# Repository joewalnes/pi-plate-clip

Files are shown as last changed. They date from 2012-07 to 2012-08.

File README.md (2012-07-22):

Pi Plate Clip
=============

An accessory for the [Adafruit's Prototyping Pi Plate](http://www.adafruit.com/products/801)
for the [Raspberry Pi](http://www.raspberrypi.org/).

These are plastic clips that can be used to add additional support, so when you push
wires into the board, it does not bend and damage the Pi connection pins.

Designed to be cut out of acryllic using a laser cutter.

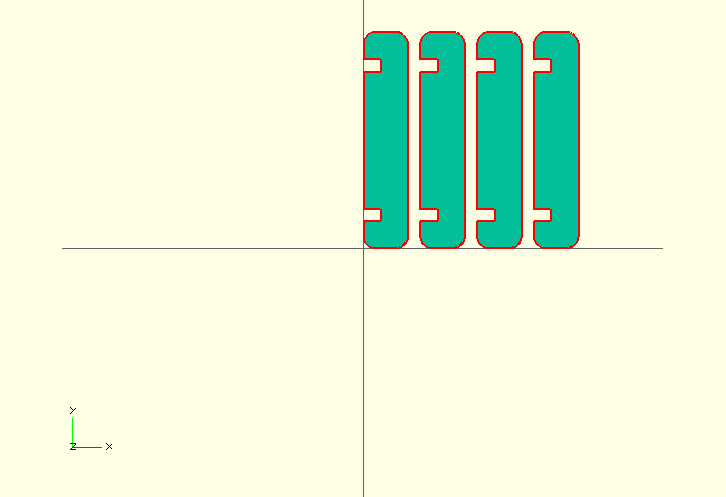
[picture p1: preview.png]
Pi Plate Clip Preview


License: [Creative Commons Attribution 3.0 Unported](http://creativecommons.org/licenses/by/3.0/)

-  **Joe Walnes**: [@joewalnes](http://twitter.com/joewalnes) | [joewalnes.com](http://joewalnes.com)

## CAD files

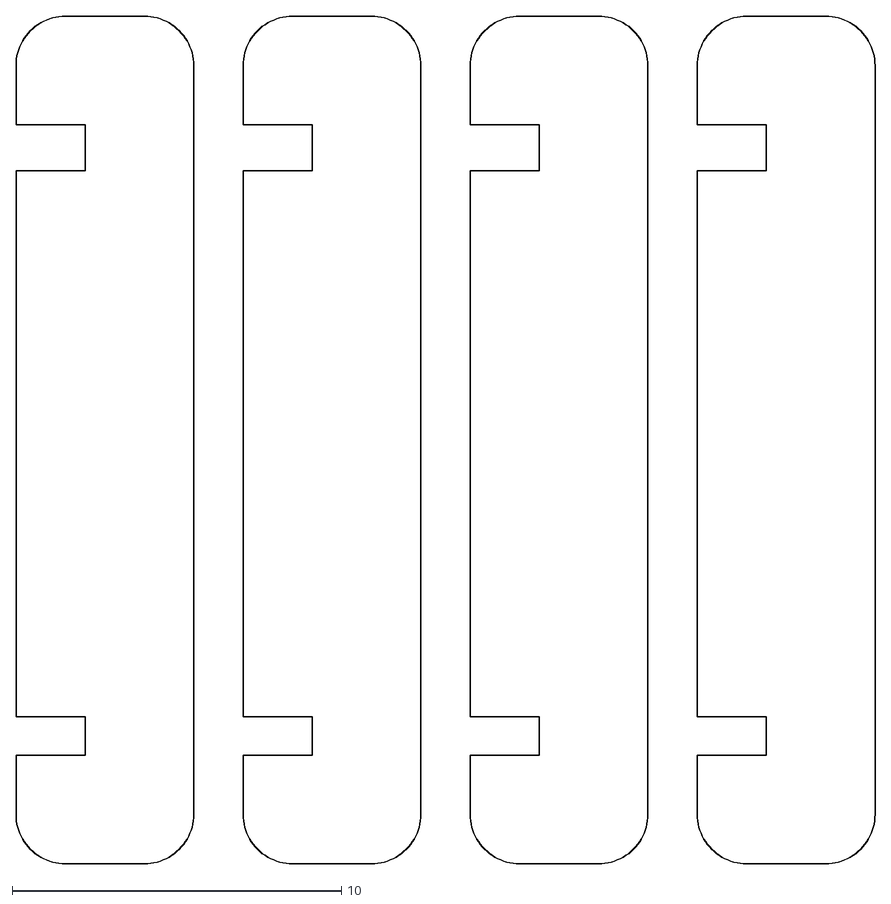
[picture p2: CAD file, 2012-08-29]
pi-plate-clip.dxf
26.1 x 25.8

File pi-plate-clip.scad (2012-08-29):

// ---------------------------------------------------------------
// PI PLATE CLIPS
// https://github.com/joewalnes/pi-plate-clip
//
// These are little clips designed to add strength to Adafruit's Prototyping Pi Plate:
// http://learn.adafruit.com/adafruit-prototyping-pi-plate
//
// They prevent the board from buckling when downwards force is applied (e.g. pushing
// wires into headers) and protect the Raspberry Pi pins.
//
// It is designed to be cut out of acyllic with a laser cutter.
//
// License: Creative Commons Attribution 3.0 Unported (CC BY 3.0)
// http://creativecommons.org/licenses/by/3.0/
// Attribution: Joe Walnes - http://joewalnes.com/


// ---------------------------------------------------------------
// DIMENSIONS and SETTINGS
// Adjust these if necessary for other boards. The default settings should work for Adafruit's Pi Plate.
// All values are in millimeters.

// Number of clips to create.
rows = 1;
cols = 4;

// Diameter of cutting tool (e.g. laser)
cutter_diameter = 0.25; // Calibrated by Epilog laser on acrylic.

// Thickness of Raspberry Pi PCB.
pi_pcb_thickness = 1.41 - cutter_diameter;

// Thickness of Pi Plate PCB (or alternative board).
plate_pcb_thickness = 1.64 - cutter_diameter;

// Vertical distance between the Raspberry Pi and the Pi Plate.
// This is the inner distance - i.e. from top of Pi to bottom of Plate.
board_space = 16.6;

// How deep to make the inset notches (horizontally).
// The deeper this is, the stronger it will be, but also more likely to collide with components
// on the boards.
inset_depth = 2.1;

// Additional vertical and horizontal distance from the edge of the notches to the
// edge of the clips. If these were zero, the clips would be useless. The larger they
// are, the stronger they are, but they also add to the total dimensions of the Pi + Plate.
vertical_padding = 3.3;
horizontal_padding = 3.3;

// How rounded the corners should be.
// This should be less than both vertical_padding and horizontal_padding.
corner_radius = 1.5;

// When creating multiple clips, how much space to leave between each one.
space_between_clips = 1.5;

// Special OpenSCAD variable to deterine resolution of curves. Specifically, how many fragments
// to break a circle down into. Higher means smoother curves. Lower means faster rendering.
// http://en.wikibooks.org/wiki/OpenSCAD_User_Manual/The_OpenSCAD_Language#.24fa.2C_.24fs_and_.24fn
$fn = 96;


// ---------------------------------------------------------------
// GEOMETRY

// Convenience function to created a rounded rectangle.
// Simplest way to do this is use a minkowski function.
module rounded_rect(w, h, corner_radius) {
	translate([corner_radius, corner_radius]) {
		minkowski() {
			circle(corner_radius);
			square([w - corner_radius * 2, h - corner_radius * 2]);
		}
	}
}

// A single clip.
module pi_plate_clip() {
	difference() {
		// Main rectangular area
		rounded_rect(
			inset_depth + horizontal_padding,
			vertical_padding + pi_pcb_thickness + board_space + plate_pcb_thickness + vertical_padding,
			corner_radius);
		// Pi PCB notch
		translate([0, vertical_padding]) {
			square([
				inset_depth,
				pi_pcb_thickness]);
		}
		// Plate PCB notch
		translate([0, vertical_padding + pi_pcb_thickness + board_space]) {
			square([
				inset_depth,
				plate_pcb_thickness]);
		}
	}
}

// Multiple clips.
for (y =[0:rows-1]) {
	for (x = [0:cols-1]) {
		translate([
			x * (inset_depth + horizontal_padding + space_between_clips),
			y * (vertical_padding + pi_pcb_thickness + board_space + plate_pcb_thickness + vertical_padding + space_between_clips)]) {
			pi_plate_clip();
		}
	}
}

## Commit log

2012-07-21 First cut at pi-plate-clips
    [pi-plate-clip.scad]
2012-07-22 Documented settings. Added license.
    [pi-plate-clip.scad]
2012-07-22 Rounded corners.
    [pi-plate-clip.scad]
2012-07-22 Multiple clips
    [pi-plate-clip.scad]
2012-07-22 Checked in .dxf to make it easy for people to use who don't need to modify it, and don't have OpenSCAD.
    [pi-plate-clip.dxf]
2012-08-29 Take into account diameter of laser.
    [pi-plate-clip.dxf, pi-plate-clip.scad]
